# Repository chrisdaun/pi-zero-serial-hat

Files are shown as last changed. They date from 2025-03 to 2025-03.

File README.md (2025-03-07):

# AqualinkD Interface Pi-HAT

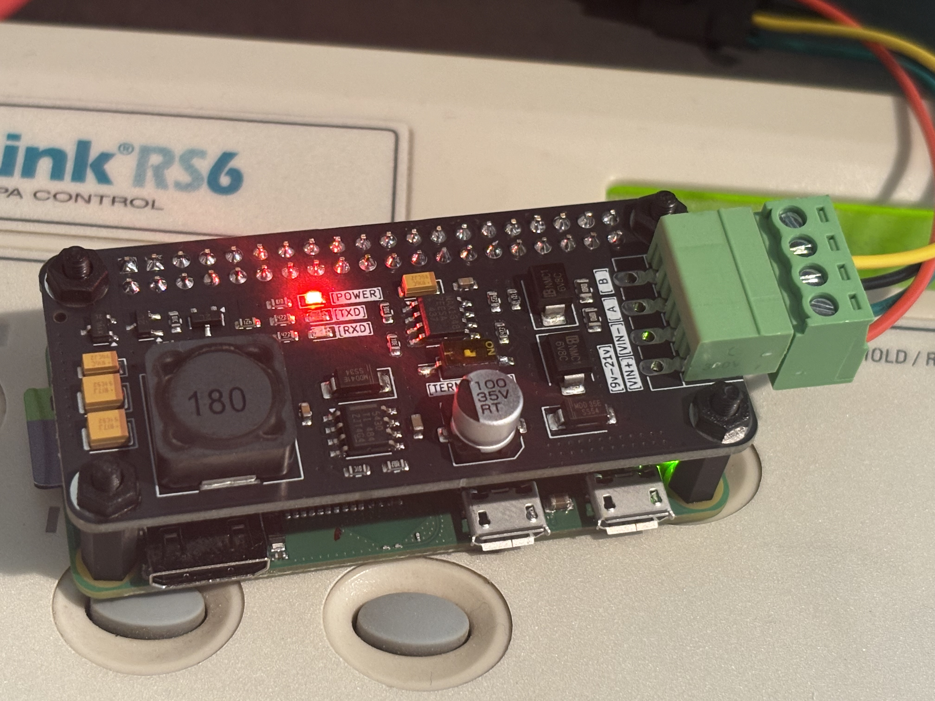
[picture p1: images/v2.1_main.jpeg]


## What is it?

A Raspberry Pi HAT compatible with Raspberry Pi and similar SBCs
<br>
It is purpose built for use with [AqualinkD](https://github.com/sfeakes/AqualinkD) and allows you to easily connect an SBC to the Aqualink Serial bus

## Technical stuff

- Communication with the Pi happens over pins 8/10 for TX/RX
- The board can power itself and the connected Pi from the Aqualink Serial bus power.
- The board has the same footprint as a Raspberry Pi Zero but also works on full size Pi boards (Pi 3, 4, 5 etc.)
- Two sets of 5.0mm mounting holes for the green Serial/Power connector allow for several connector options (horizontal flush/horizontal offset/vertical)

## Where can I get one?

I may offer premade boards in the future but for now:
<br>
You can use the files in the KiCAD/fabrication folder to have preassembled boards made at jlcpcb.com
<br>

Note: Due to the way some components are oriented in jlcpcb's component reels, you may need to adjust the component rotation at the interactive board review stage when ordering. You may need to rotate the part at this point until the part's pin 1 designator lines up with the pin 1 designator on the board. This seems to be most common with the following components:

- U1 - Usually needs to be rotated 90 deg. clockwise
- Q1, Q2 and Q3 - Usually needs to be rotated 180 deg.
- J2 - This component is a switch and can be rotated 90 deg. either way if needed

You'll need to source a 40pin GPIO female header and a 3.50mm 4 position screw terminal and solder them on to complete the board.

- [40pin GPIO female header - 2x20P 2.54mm pitch](https://a.aliexpress.com/_mOcIEMF)
  <br>
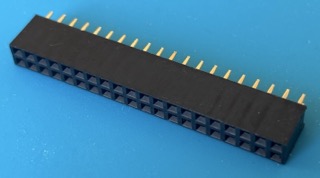
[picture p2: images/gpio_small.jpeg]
  

- [4 position screw terminal - 3.50mm pitch vertical or right angle](https://a.aliexpress.com/_m0hhCc7)
  <br>
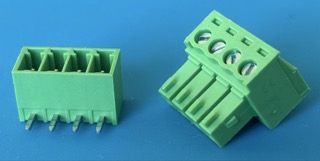
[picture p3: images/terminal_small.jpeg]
  

## Software Setup

### Raspberry Pis running Raspbian

1. Run raspi-config with sudo: `sudo raspi-config`
2. Navigate to `Interface Options`
3. Navigate to `Serial Port`
4. Select `No` when asked if you would like a login shell to be accessible over serial **If you skip this step, aqualinkd will not work**
5. Select `Yes` when asked if you would like the serial port hardware enabled
6. Select `Ok`
7. Exit raspi-config
8. Reboot
9. Edit aqualinkd.conf with sudo: `sudo vim /etc/aqualinkd.conf`
10. Set the serial_port variable to use Serial0: `serial_port=/dev/ttyS0`

### Raspberry Pis running other OSs/Other Single Board Computers

Some SBCs like the [Orange Pi Zero 2W](http://www.orangepi.org/html/hardWare/computerAndMicrocontrollers/service-and-support/Orange-Pi-Zero-2W.html) and similar have the debug serial console enabled on GPIO pins 8/10 in their images. Serial communication will not work in this configuration and the debug serial console needs to be disabled. This is usually not trivial a varies by SBC so I won't provide guidance on how to do it here.

##

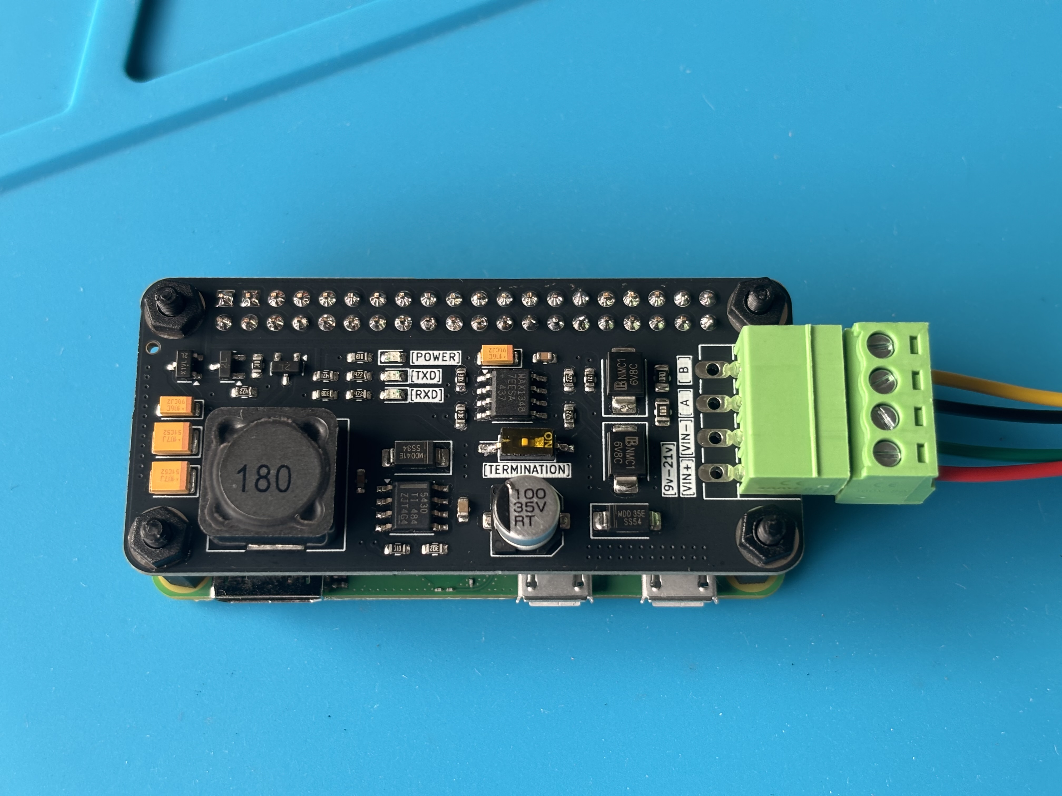
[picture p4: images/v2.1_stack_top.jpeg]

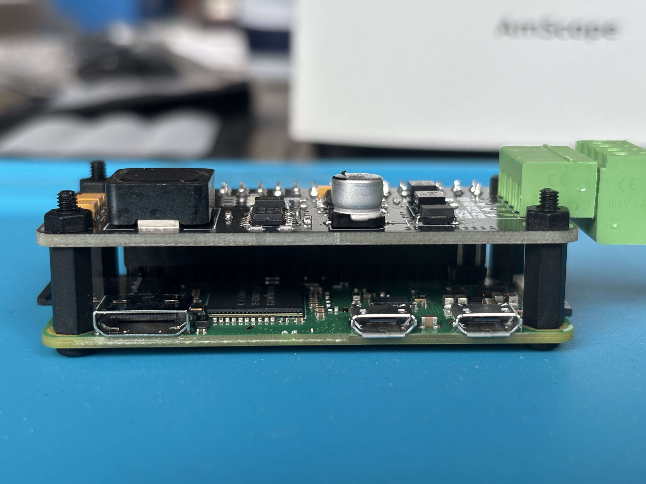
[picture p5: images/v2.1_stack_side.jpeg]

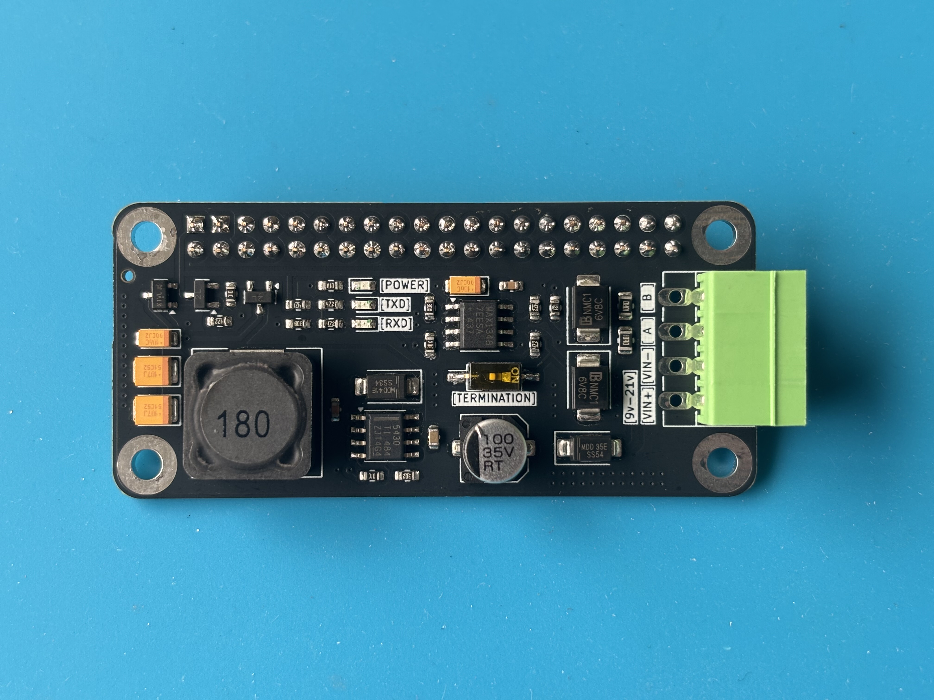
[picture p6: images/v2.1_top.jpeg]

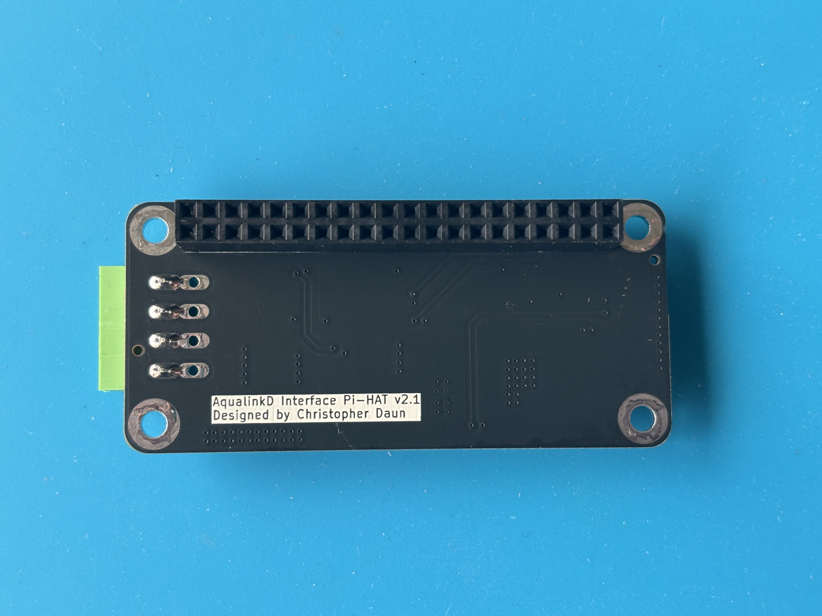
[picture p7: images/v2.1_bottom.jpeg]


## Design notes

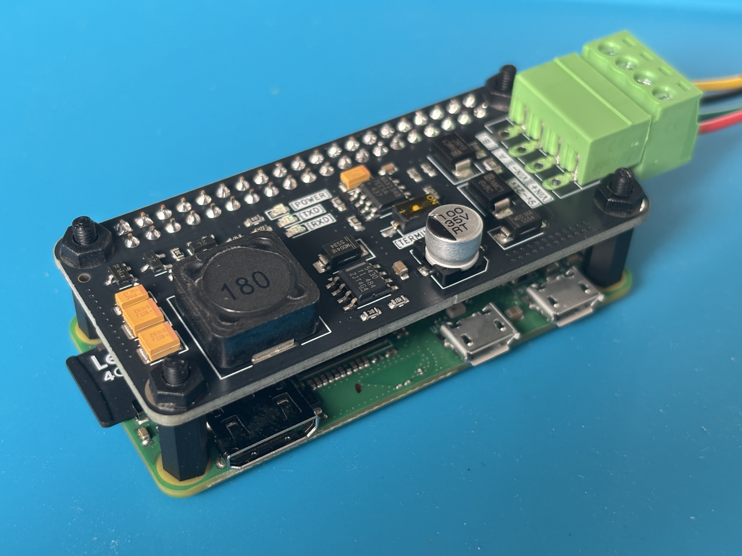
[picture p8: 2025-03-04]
images/v2.1_top_angle.jpeg

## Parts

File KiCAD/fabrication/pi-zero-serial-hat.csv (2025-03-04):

Value | JLCPCB Part # | DNP | Description | Comment | Designator | Ref | Footprint
TPS5430DDA | C9864 |  | 3A, Step Down Swift Converter, Adjustable Output Voltage, 5.5-36V Input Voltage, PowerSO-8 | Step-down type Adjustable 1.221V~32.04V 3A 5.5V~36V SOIC-8-EP DC-DC Converters ROHS | U2 |  | Package_SO:TI_SO-PowerPAD-8_ThermalVias
MAX13487EESA+ | C143342 |  |  | Transceiver 500Kbps 1/1 SOIC-8 RS-485 / RS-422 ICs ROHS | U1 |  | Package_SO:SOIC-8_3.9x4.9mm_P1.27mm
1kΩ | C21190 |  | Resistor | 100mW Thick Film Resistors 75V ±100ppm/℃ ±1% 1kΩ 0603 Chip Resistor - Surface Mount ROHS | R16 |  | Resistor_SMD:R_0603_1608Metric
3kΩ | C4211 |  | Resistor | 100mW Thick Film Resistors 75V ±100ppm/℃ ±1% 3kΩ 0603 Chip Resistor - Surface Mount ROHS | R15 |  | Resistor_SMD:R_0603_1608Metric
10kΩ | C25804 |  | Resistor | 100mW Thick Film Resistors 75V ±100ppm/℃ ±1% 10kΩ 0603 Chip Resistor - Surface Mount ROHS | R14 |  | Resistor_SMD:R_0603_1608Metric
4.7kΩ | C23162 |  | Resistor | 100mW Thick Film Resistors 75V ±100ppm/℃ ±1% 4.7kΩ 0603 Chip Resistor - Surface Mount ROHS | R13 |  | Resistor_SMD:R_0603_1608Metric
2kΩ | C22975 |  | Resistor |  | R12 |  | Resistor_SMD:R_0603_1608Metric
470Ω | C23179 |  | Resistor |  | R11 |  | Resistor_SMD:R_0603_1608Metric
4.7kΩ | C23162 |  | Resistor |  | R10 |  | Resistor_SMD:R_0603_1608Metric
4.7kΩ | C23162 |  | Resistor |  | R9 |  | Resistor_SMD:R_0603_1608Metric
20Ω | C22950 |  | Resistor |  | R8 |  | Resistor_SMD:R_0603_1608Metric
4.7kΩ | C23162 |  | Resistor |  | R7 |  | Resistor_SMD:R_0603_1608Metric
10kΩ | C25804 |  | Resistor |  | R6 |  | Resistor_SMD:R_0603_1608Metric
10Ω | C17415 |  | Resistor |  | R5 |  | Resistor_SMD:R_0805_2012Metric
120Ω | C22787 |  | Resistor |  | R4 |  | Resistor_SMD:R_0603_1608Metric
10Ω | C17415 |  | Resistor |  | R3 |  | Resistor_SMD:R_0805_2012Metric
20Ω | C22950 |  | Resistor |  | R2 |  | Resistor_SMD:R_0603_1608Metric
4.7kΩ | C23162 |  | Resistor |  | R1 |  | Resistor_SMD:R_0603_1608Metric
MMBT5401 | C8326 |  | Bipolar transistor symbol for simulation only, substrate tied to the emitter | 150V 300mW 200@10mA,5V 600mA PNP SOT-23 Bipolar (BJT) ROHS | Q3 |  | Package_TO_SOT_SMD:SOT-23
MMBT5401 | C8326 |  | Bipolar transistor symbol for simulation only, substrate tied to the emitter | 150V 300mW 200@10mA,5V 600mA PNP SOT-23 Bipolar (BJT) ROHS | Q2 |  | Package_TO_SOT_SMD:SOT-23
AO3401A | C15127 |  | -4.0A Id, -30V Vds, P-Channel MOSFET, SOT-23 | 30V 4A 44mΩ@10V,4.3A 1.4W 1.3V@250uA 1 Piece P-Channel SOT-23 MOSFETs ROHS | Q1 |  | Package_TO_SOT_SMD:SOT-23
18uH | C329749 |  | Inductor |  | L1 |  | Inductor_SMD:L_Sunlord_SWRB1204S
SW_DIP_x01 | C18078237 |  | 1x DIP Switch, Single Pole Single Throw (SPST) switch, small symbol |  | J2 |  | Button_Switch_SMD:SW_DIP_SPSTx01_Slide_Copal_CHS-01B_W7.62mm_P1.27mm
D | C22452 |  | Diode |  | D7 |  | Diode_SMD:D_SMA
LED | C2286 |  | Light emitting diode |  | D6 |  | LED_SMD:LED_0603_1608Metric
B340 | C8678 |  | 40V 3A Schottky Barrier Rectifier Diode, SMC |  | D5 |  | Diode_SMD:D_SMA
LED_RXD | C2286 |  | Light emitting diode |  | D4 |  | LED_SMD:LED_0603_1608Metric
LED_TXD | C2286 |  | Light emitting diode |  | D3 |  | LED_SMD:LED_0603_1608Metric
SMBJ6.8CA | C78395 |  | Bidirectional transient-voltage-suppression diode |  | D2 |  | Diode_SMD:D_SMB
SMBJ6.8CA | C78395 |  | Bidirectional transient-voltage-suppression diode |  | D1 |  | Diode_SMD:D_SMB
10uF | C96446 |  | Unpolarized capacitor |  | C8 |  | Capacitor_SMD:C_0603_1608Metric
100uF 35V | C3445235 |  | 100uF 35V 120mA@120Hz ±20% SMD,D6.3xL5.4mm Aluminum Electrolytic Capacitors - SMD ROHS |  | C7 |  | Capacitor_SMD:C_Elec_6.3x5.4
100uF | C16133 |  | Polarized capacitor |  | C6 |  | Capacitor_Tantalum_SMD:CP_EIA-3528-21_Kemet-B
100uF | C16133 |  | Polarized capacitor |  | C5 |  | Capacitor_Tantalum_SMD:CP_EIA-3528-21_Kemet-B
10uf | C7171 |  | Polarized capacitor |  | C4 |  | Capacitor_Tantalum_SMD:CP_EIA-3216-18_Kemet-A
10nF | C57112 |  | Unpolarized capacitor |  | C3 |  | Capacitor_SMD:C_0603_1608Metric
100nF | C14663 |  | Unpolarized capacitor |  | C2 |  | Capacitor_SMD:C_0603_1608Metric
10uF | C7171 |  | Unpolarized capacitor |  | C1 |  | Capacitor_Tantalum_SMD:CP_EIA-3216-18_Kemet-A

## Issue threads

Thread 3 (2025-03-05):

Question about ordering from JLCPCB

mal7887, 2025-03-05:
First of all, Awesome project and thank you for sharing. I'm not an expert at ordering PCB components. I am comparing your image to the 3d Image generated from the uploaded files. It looks like J2 Is rotated 90 degrees the wrong way. Seems like a simple enough fix, but wanted to confirm before I order.

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

chrisdaun, 2025-03-05:
Hey thanks 😊
It's been a fun project.
I've been working with the creator of [AqualinkD](https://github.com/sfeakes/AqualinkD) on this and he's got some really cool 3D printed cases in the works. We're just ironing out the final designs.

The part rotation is based on the fabricator's part reel and the part orientation. Sometimes that differs per reel. Usually the jlcpcb tech will correct it for you but never hurts play it safe and fix it before you submit an order.
Looking at your image you can rotate J2 90 degrees in either direction. Looks like you'll also need:
- Rotate Q1, Q2 and Q3 180 degrees
- Rotate U1 clockwise 90 degrees

What Raspberry Pi or similar single board computer did you plan to use this with? And would you be interested in a pre-built board instead of getting a batch fabricated?

mal7887, 2025-03-06:
That would be awesome!

I am running on a pi zero 2. Getting a prebuilt sounds much easier. Happy to hear a case is coming too!

chrisdaun, 2025-03-06:
Shoot me an email, should be public on my GitHub profile.

Closed 2025-03-06.

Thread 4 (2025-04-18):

Help with JLCPCB Placement file please.

AUPoolUser, 2025-04-18:
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

Hello,

thanks for your great project - I am looking forward to receiving these pcb's. I am just ordering with JLCPCB and along with the rotation of Q1,Q2,Q3,U1 and J1 that you mention, U2 and L1 appeared to require adjusting also - which I have done.

Could you advise if the above is correct along with the LED polarity?

Also - could I suggest that you maybe upload this schematic available from JLCPCB to assist others.

Many Many Many Thanks.

chrisdaun, 2025-04-18:
The LED polarity is correct (the power led polarity should be the opposite of the RXD/TXD like you have it)
Looks like you have everything correct except L1
L1 needs to be rotated back to the right 90 deg.

You can use this image as a reference for the correct rotations of all the parts
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

AUPoolUser, 2025-04-18:
Thank you for the quick reply. I appreciate it very much.

Thanks again for the project.

chrisdaun, 2025-04-18:
> Thank you for the quick reply. I appreciate it very much.
>
> Thanks again for the project.

No problem! :)

Closed 2025-04-18.

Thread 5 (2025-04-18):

Where can I get your pi-zero-serial-hat and case?

jkosharek, 2025-04-18:
Where can I get your pi-zero-serial-hat and case?

chrisdaun, 2025-04-18:
> Where can I get your pi-zero-serial-hat and case?

Hey @jkosharek,
Looks like [sfeakes](https://github.com/sfeakes) replied in [this thread](https://github.com/aqualinkd/AqualinkD/discussions/336)

He has a few hats on hand and produces the cases.
Let me know if he gets you sorted :)

Closed 2025-04-20.

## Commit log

2024-11-13 Footprint updates
    [pi-zero-serial-hat-B_Cu.gbr, pi-zero-serial-hat-B_Mask.gbr, pi-zero-serial-hat-B_Paste.gbr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]
2024-11-25 Updated terminal footprint and some trace routing
    [pi-zero-serial-hat.kicad_pcb, pi-zero-serial-hat.kicad_sch]
2024-11-26 New board design
    [pi-zero-serial-hat.kicad_pcb, pi-zero-serial-hat.kicad_sch]
2024-11-27 Added schematic from reversed board
2024-11-28 Updated combo board design
    [pi-zero-serial-hat-B_Cu.gbr, pi-zero-serial-hat-B_Mask.gbr, pi-zero-serial-hat-B_Paste.gbr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]
2024-11-30 Layout update
    [pi-zero-serial-hat-B_Cu.gbr, pi-zero-serial-hat-B_Mask.gbr, pi-zero-serial-hat-B_Paste.gbr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]
2024-12-20 Updated component values for BOM
    [pi-zero-serial-hat-B_Cu.gbr, pi-zero-serial-hat-B_Mask.gbr, pi-zero-serial-hat-B_Paste.gbr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]
2024-12-21 Redesigned the buck converter circuit to us the TI TPS5430DDAR part
    [pi-zero-serial-hat-B_Cu.gbr, pi-zero-serial-hat-B_Mask.gbr, pi-zero-serial-hat-B_Paste.gbr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]
2024-12-24 Updated board size and lazy routing
    [pi-zero-serial-hat.kicad_pcb, pi-zero-serial-hat.kicad_sch]
2024-12-24 Updated fabrication files
    [pi-zero-serial-hat-B_Cu.gbr, pi-zero-serial-hat-B_Mask.gbr, pi-zero-serial-hat-B_Paste.gbr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]
2025-01-02 Remapped TX/RX to pins 8/10 and removed solder jumper pads
    [pi-zero-serial-hat.kicad_pcb, pi-zero-serial-hat.kicad_sch]
2025-01-02 Updated layout to fit on a single sided zero form factor board
    [pi-zero-serial-hat.kicad_pcb]
2025-01-02 Generated new fabrication files
    [pi-zero-serial-hat-B_Cu.gbr, pi-zero-serial-hat-B_Mask.gbr, pi-zero-serial-hat-B_Paste.gbr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]
2025-01-15 Changed BUCK voltage divider to set VOUT to 5.291v
    [pi-zero-serial-hat.kicad_sch]
2025-01-24 Design cleanup
    [pi-zero-serial-hat-B_Cu.gbr, pi-zero-serial-hat-B_Mask.gbr, pi-zero-serial-hat-B_Paste.gbr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]
2025-02-02 Updated component layout and silkscreen
    [pi-zero-serial-hat-B_Cu.gbr, pi-zero-serial-hat-B_Mask.gbr, pi-zero-serial-hat-B_Paste.gbr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]
2025-02-02 Updated board revision and added component comments
    [pi-zero-serial-hat.kicad_pcb, pi-zero-serial-hat.kicad_sch]
2025-02-02 Added option to use dip switch or pin jumper for termination
    [pi-zero-serial-hat.kicad_pcb, pi-zero-serial-hat.kicad_sch]
2025-02-03 Updated input capacitor component
    [pi-zero-serial-hat-B_Cu.gbr, pi-zero-serial-hat-B_Mask.gbr, pi-zero-serial-hat-B_Paste.gbr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]
2025-02-09 Cleaned up component and silkscreen layout
    [pi-zero-serial-hat.kicad_pcb]
2025-02-10 A few minor updates
    [pi-zero-serial-hat.kicad_pcb]
2025-02-11 Termination switch placement testing
    [pi-zero-serial-hat-B_Cu.gbr, pi-zero-serial-hat-B_Mask.gbr, pi-zero-serial-hat-B_Paste.gbr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]
2025-03-04 Finished populating the BOM item descriptions and data sheet links
    [pi-zero-serial-hat.kicad_sch]
2025-03-04 Removing KiCAD auto backups
